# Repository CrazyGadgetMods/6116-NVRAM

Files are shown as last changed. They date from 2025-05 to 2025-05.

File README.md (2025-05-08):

# 6116 NVRAM

This is an opensource NVRAM replacement for 6116 RAM used in Williams System 11 / System 9, Bally System 9, and some Data East games.  

I did not make an official BOM for this since there are so few components.  
The values are as follows (with DigiKey hyperlinks):  
U1: [FM16W08-SG](https://www.digikey.com/en/products/detail/infineon-technologies/FM16W08-SG/4090348)  
C1: [10µF 0603 16V](https://www.digikey.com/en/products/detail/samsung-electro-mechanics/CL10X106MO8NRNC/5961253) (or equivalent)  
R1, R2: [10kΩ 0603 1%](https://www.digikey.com/en/products/detail/bourns-inc/CR0603-FX-1002ELF/3593188) (or equivalent)  
Headers (x2): [12-Pin Header 0.1" (2.54mm) pitch](https://www.digikey.com/en/products/detail/adam-tech/PH1-12-UA/9830395) (or equivalent)  
IC Socket: [24-Pin DIP Socket 0.1" (2.54mm) pitch](https://www.digikey.com/en/products/detail/adam-tech/ICS-624-T/9832867) (or equivalent)  

Renders:  
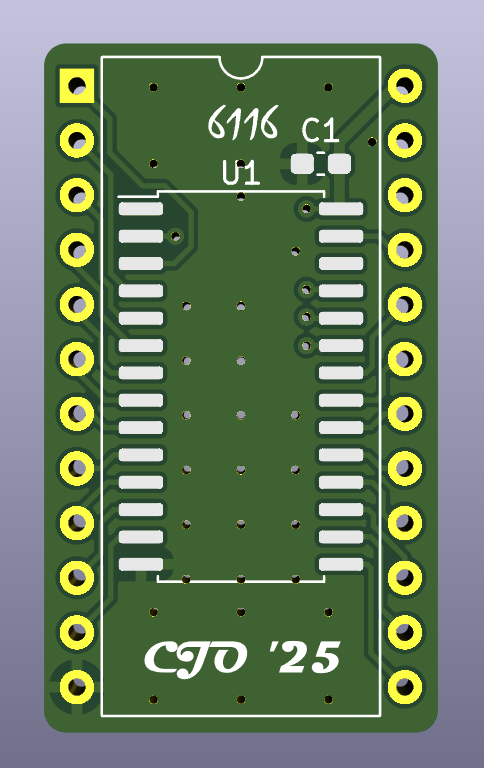
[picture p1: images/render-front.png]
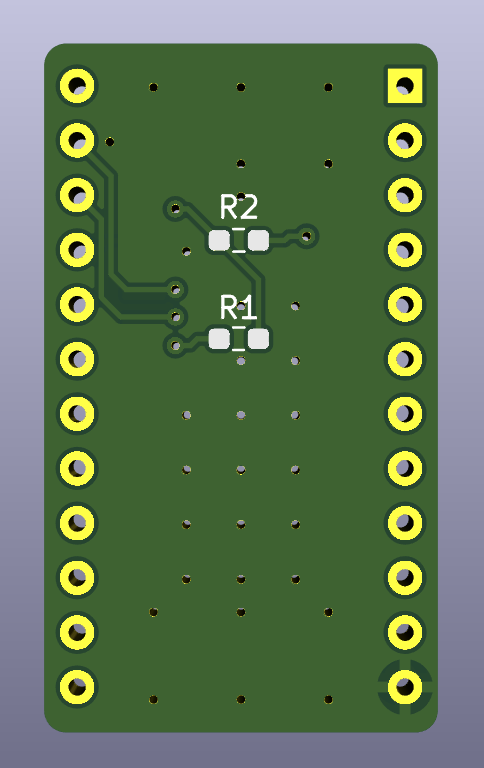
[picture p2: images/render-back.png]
 

Assembled Board:  
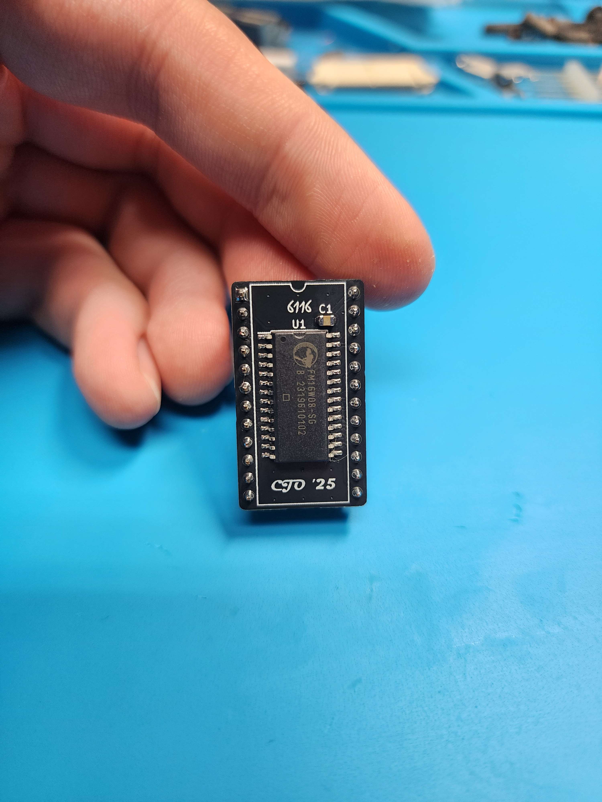
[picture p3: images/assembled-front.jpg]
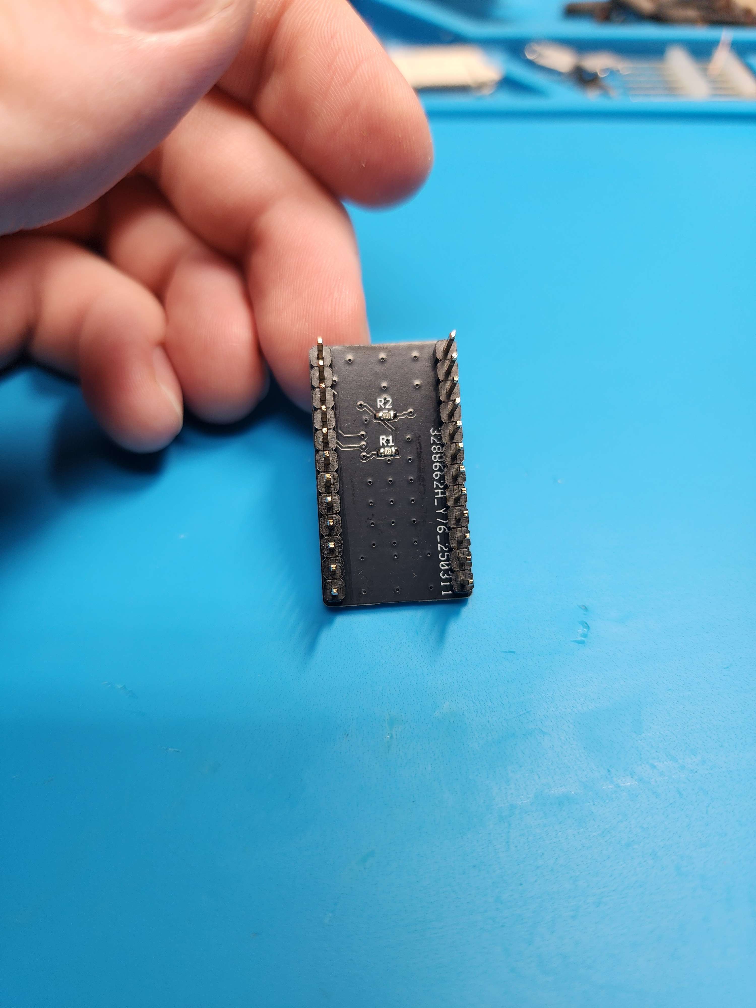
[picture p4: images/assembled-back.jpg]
 

Installation in Williams System 11 Grand Lizard:  
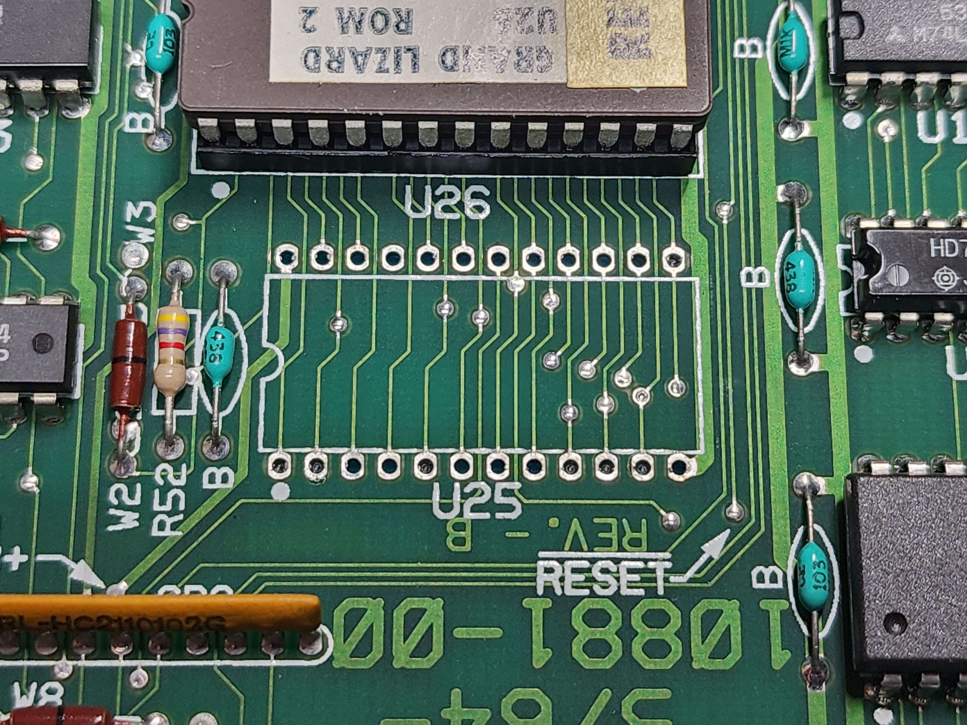
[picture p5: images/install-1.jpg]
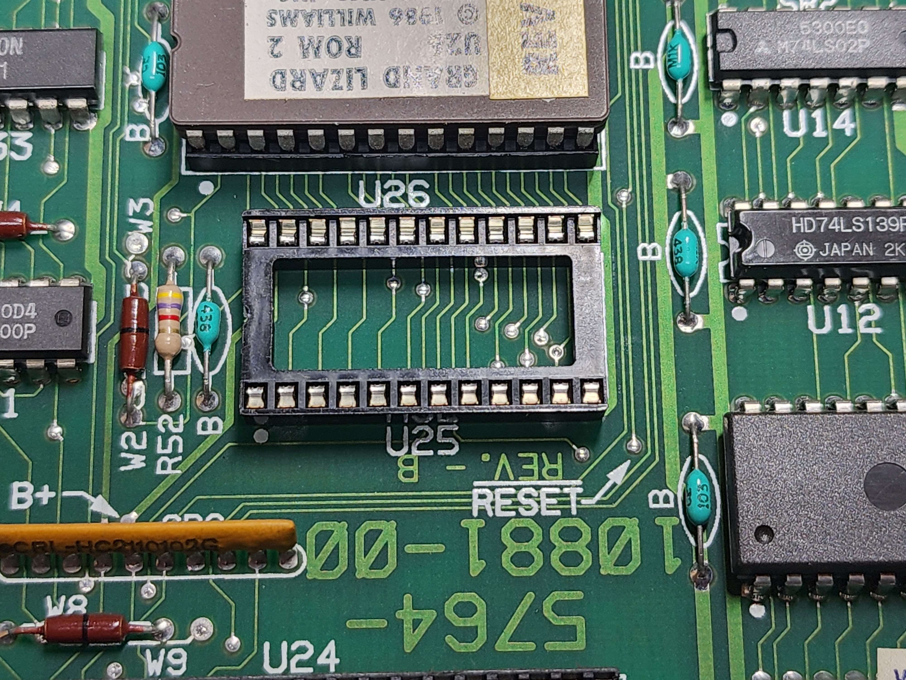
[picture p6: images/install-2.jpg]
 
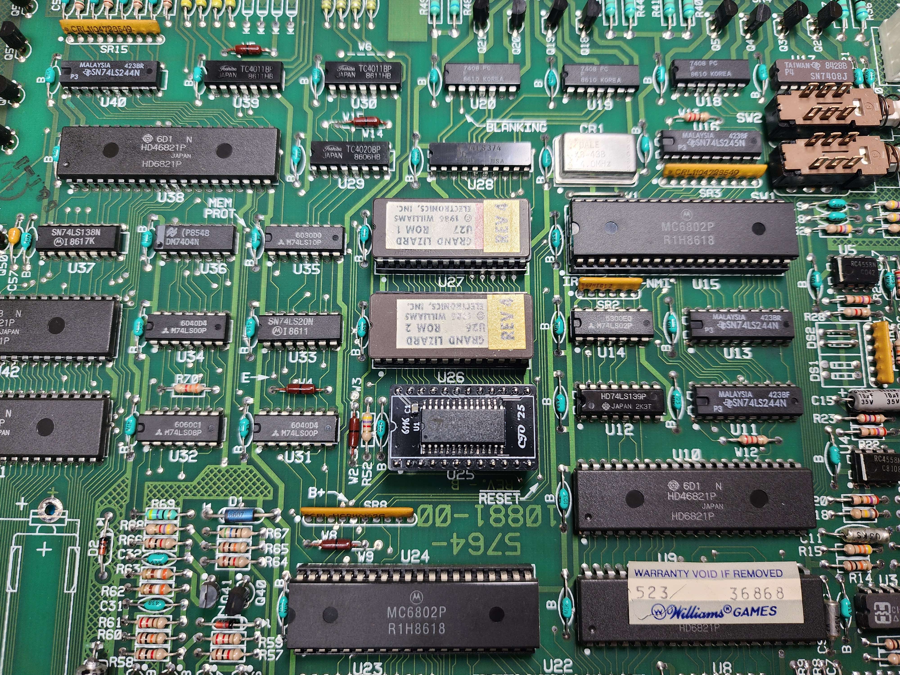
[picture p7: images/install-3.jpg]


## Credits
- SonnyJim: Helping me understand how to transpose the FM16W08 to a 6116 pinout.
- [Pinball People Discord](https://discord.com/invite/XffPx6VKTv): Being a wonderful, helpful community.
- [Pinside](https://pinside.com/): Being the best pinball community out there, and a cornucopia of knowledge!

## License
Solderpad Hardware License v2.1

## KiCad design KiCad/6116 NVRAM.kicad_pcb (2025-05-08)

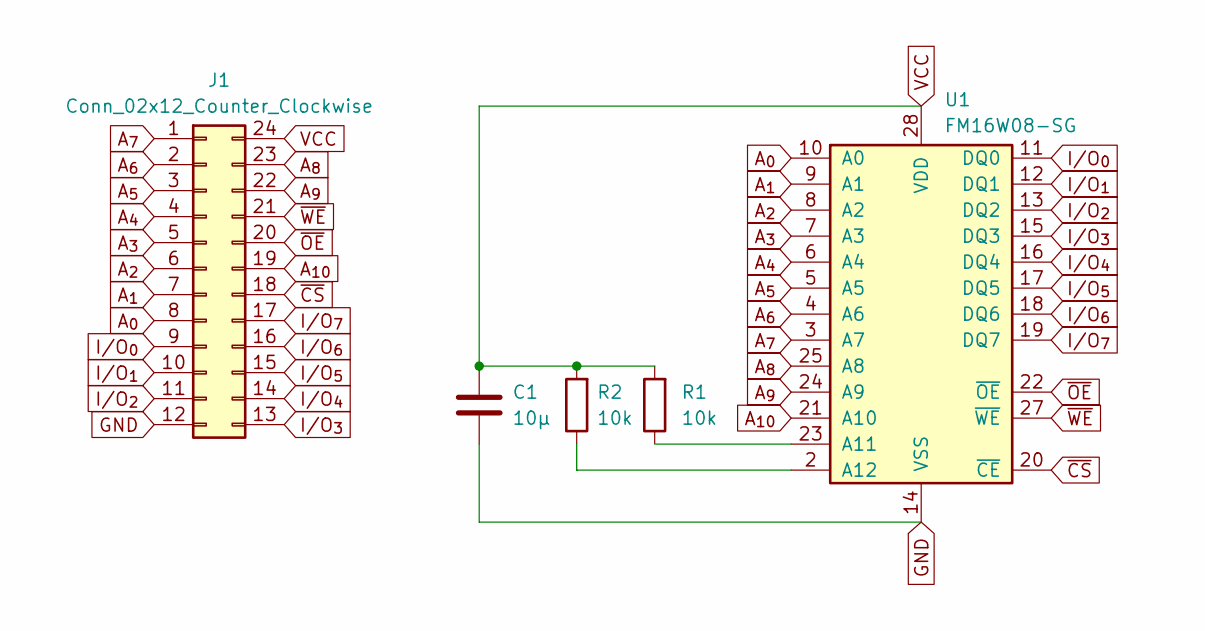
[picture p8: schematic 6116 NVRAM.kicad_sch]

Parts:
C1: 10µ; C_0603_1608Metric_Pad1.08x0.95mm_HandSolder
J1: Conn_02x12_Counter_Clockwise; DIP-24_W15.24mm
R1, R2: 10k; R_0603_1608Metric_Pad0.98x0.95mm_HandSolder
U1: FM16W08-SG; SOIC-28W_7.5x17.9mm_P1.27mm

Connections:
A_{0}: J1.8, U1.10 (A0)
A_{1}: J1.7, U1.9 (A1)
A_{2}: J1.6, U1.8 (A2)
A_{3}: J1.5, U1.7 (A3)
A_{4}: J1.4, U1.6 (A4)
A_{5}: J1.3, U1.5 (A5)
A_{6}: J1.2, U1.4 (A6)
A_{7}: J1.1, U1.3 (A7)
A_{8}: J1.23, U1.25 (A8)
A_{9}: J1.22, U1.24 (A9)
A_{10}: J1.19, U1.21 (A10)
GND: C1.2, J1.12, U1.14 (VSS)
I/O_{0}: J1.9, U1.11 (DQ0)
I/O_{1}: J1.10, U1.12 (DQ1)
I/O_{2}: J1.11, U1.13 (DQ2)
I/O_{3}: J1.13, U1.15 (DQ3)
I/O_{4}: J1.14, U1.16 (DQ4)
I/O_{5}: J1.15, U1.17 (DQ5)
I/O_{6}: J1.16, U1.18 (DQ6)
I/O_{7}: J1.17, U1.19 (DQ7)
unnamed: R1.1, U1.23 (A11)
unnamed: R2.1, U1.2 (A12)
VCC: C1.1, J1.24, R1.2, R2.2, U1.28 (VDD)
~CS: J1.18, U1.20 (~CE)
~OE: J1.20, U1.22 (~OE)
~WE: J1.21, U1.27 (~WE)

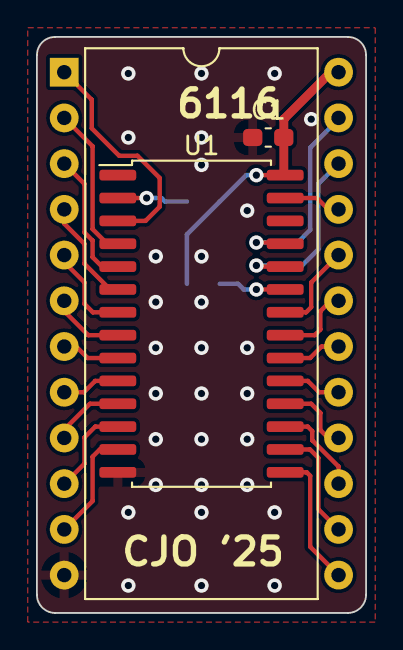
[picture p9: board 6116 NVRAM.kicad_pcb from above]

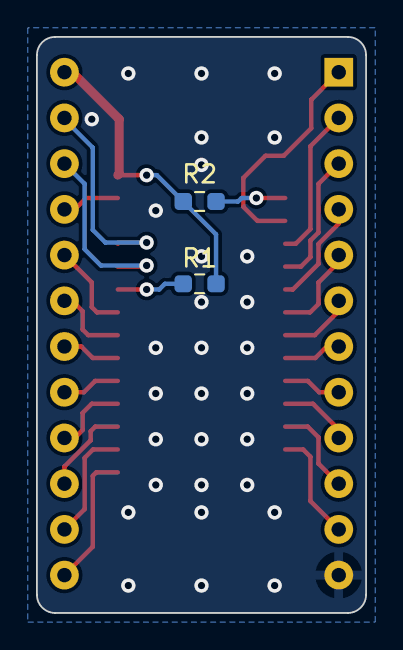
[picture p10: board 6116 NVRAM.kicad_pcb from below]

Board: 2 copper layers, 18.3 x 32.0 mm, 5 parts (2 on the bottom side), 26 nets.
